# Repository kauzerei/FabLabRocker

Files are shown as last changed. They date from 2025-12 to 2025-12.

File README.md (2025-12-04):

# FabLabRocker

A simple servo-based lab rocker with variable frequency and amplitude.
Designed for DIY PCB fabrication, but can be used for large format photography or chemistry.
3d-design is customizable, written in OpenSCAD and BOSL2.
Measure your container and make the parts that fit ideally.

## PCB

PCB is as simple as it can get.
The project is all about DIY PCB fabrication, so of course it is.
It is one-sided and basically connects a ready-made modules.
Power from a cell does through a switch to DC-DC converter that powers Arduino and the servo.
Two potentiometers are wired to 0 and 5v rails and to analog inputs of Arduino.

### PCB parts list

- Arduino Nano or Pro Micro (change analog pins in code)
- 2 linear Potentiometers, Piher T 16..H or similar, about 25k
- mini DC-DC converter module (noname asymmetric one, based around SDB628xx)
- MG90S Servo
- Any toggle switch to be mounted in 7mm hole
- 18650 holder and cell
- Pin headers/sockets to connect the servo and the switch

## Other parts needed

- 6 M2 thread inserts and 2 M2x8 are nice to have, but not strictly necessary.
- 2 M4x8 screws for the rocking joint. Can also be replaced with almost anything. 

## 3d-printed parts

### Modifying with OpenSCAD

Printable files in STL format are included in this repo.
The ```rocker_top``` should be generated by the user most likely to fit the container.
It's not too scary even if you don't know anything about OpenSCAD.

After installing OpenSCAD run ```git submodule update --init``` and open ```rocker.scad```.
There is "customizer" panel in GUI where you can change the parameters

Model parameters are grouped into self-explanatory categories.
most important are ```bath_width```, ```bath_depth``` which are measurements of container bottom, and ```bath_rounding``` and ```bath_chamfer```, which define corner rounding of the container.
Of the last two parameters only one can be non-zero.

### Printing

Print in default orientation.
2 walls with 30% infill seems fine.
Maybe 3 walls for heavier container with more liquid.

For the ```top_mech``` part use organic supports for the gear.
Other parts are fine without supports.

## Assembly

Assemble the PCB.
KiCad project is in ```agitator_pcb```.

I mounted boost module using pin headers, but any thick wire will do.
I soldered wires and pins to the switch, and pin sockets to the board.
Soldering directly is also OK.
Don't forget to set the voltage of DC-DC converter to 5v.

Customize the mechanical parts and print them.
For the top assembly use 4 thread inserts in ```top_mech```, for mounting the motor use 2 in ```bottom``` and matching M2x8 screws.
Or don't. You can use self-tapping screws or glue or whatever.
The moveable joints are formed by two M4x8 screws.
Any pins 4mm in diamter and 8mm or longer glued to the moving part would be OK.
Press the gear to the shaft of the motor, but fix it with the screw only after the tests.
Mid position of the servo should correspond to horizontal position of the platform.
Fix the gear with M2.5 screw, that comes with each servo when it is oriented correctly. 
PCB is held by the pots, put them through the holes in the enclosure and fix with nuts.

The rocking mechanics just rests on top of the enclosure not beig fixed.
If it bothers you, you can just glue it.
The cell should still be accessible if you do it.  

### Usage

One pot changes the oscillation frequency, the other controls amplitude.
High amplitudes are not achievable with high frequencies.
At high frequencies servo does not have time to rotate to goal positions.
I kept the high frequencies as an imitation of vibrating plate at low amplitudes.

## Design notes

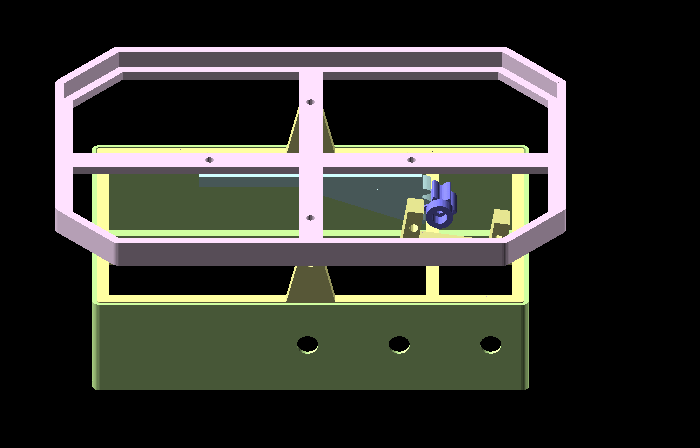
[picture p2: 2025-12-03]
img/animated.gif

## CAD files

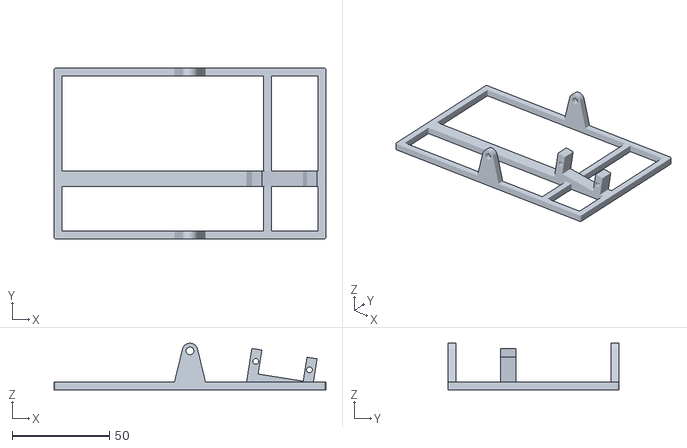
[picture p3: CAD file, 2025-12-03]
3d_print/stl/rocker_bottom.stl
140.0 x 88.0 x 24.0

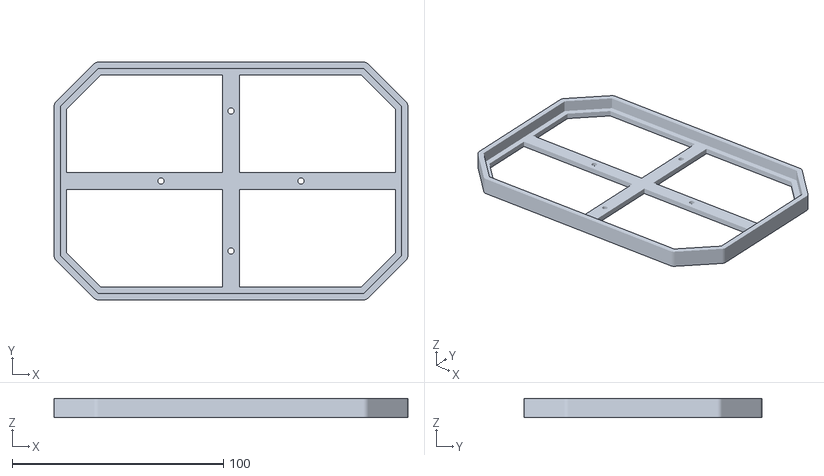
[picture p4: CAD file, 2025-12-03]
3d_print/stl/rocker_top.stl
167.5 x 112.5 x 9.00

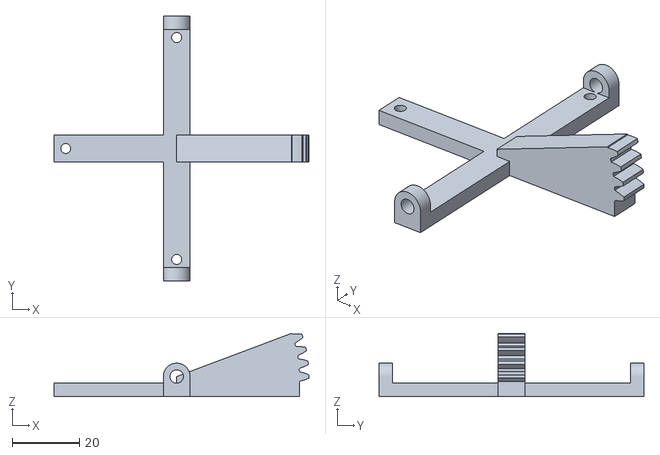
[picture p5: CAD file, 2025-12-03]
3d_print/stl/rocker_top_mech.stl
76.1 x 79.0 x 18.9

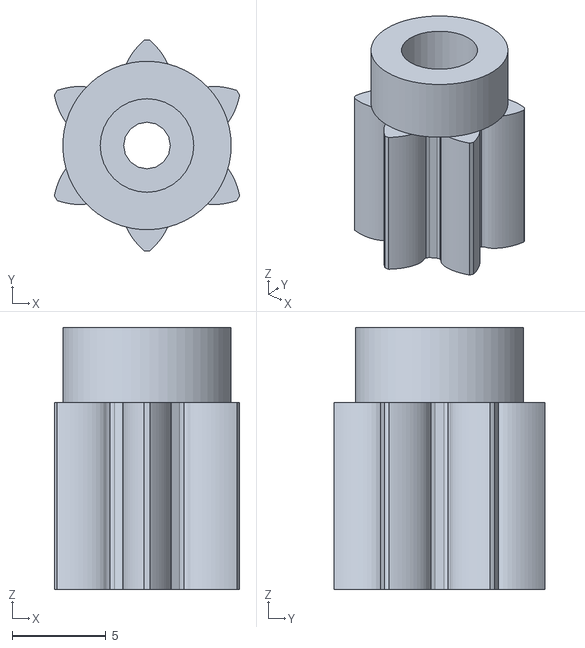
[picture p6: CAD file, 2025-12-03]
3d_print/stl/rocker_servo_gear.stl
9.90 x 11.3 x 14.0

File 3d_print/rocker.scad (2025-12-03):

include <BOSL2/std.scad>
include <BOSL2/gears.scad>
$fa=1/2;
$fs=1/2;
bsl=1/100;

part="NOSTL_all";//[NOSTL_all,top,top_mech,bottom,servo_gear,enclosure]

/* [base (where servo is mounted)] */
base_width=140;
base_depth=88;
base_thickness=4;
base_rounding=1;
height=20;
eyelet_d=4;
eyelet_w=16;
eyelet_gap=0.5;
servo_d=5;
servo_ax=4;
servo_mount_thickness=8;
horn_screw=4;
horn_thickness=1.6;

/* [container holder parameters] */
bath_width=161.5;
bath_depth=106.5;
bath_thickness=3;
bath_lip=6;
bath_rounding=0;//15;
bath_chamfer=18;

/* [general mechanical parameters] */
wall=2; //thinnest load-bearing wall around holes
mech_thickness=4;
screw_d=3; //holes for thread inserts and such
gear_gap=0.0; //extra air between gears
servo_gear=6; //number of teeth
gear_ratio=10; 
gear_pitch=4;
gear_thickness=10;

/* [enclosure] */
enclosure_gap=0.5;
enclosure_wall=1.2;
enclosure_h=25;
holes=[[41,17],[71,17],[11,17]];
hole_d=7;

screw_offset=eyelet_d/2+2*wall+screw_d/2;
dist=gear_dist(circ_pitch=gear_pitch,teeth1=servo_gear,teeth2=servo_gear*gear_ratio)+gear_gap;
max_rotation=90/gear_ratio;
global_rotation=sin(1800*$t)*max_rotation; //to be used in animation maybe
servo_position=[dist*cos(90/gear_ratio),-gear_thickness/2,-dist*sin(90/gear_ratio)];
thickness=eyelet_d+2*wall; //width of parts around eyelets on top and base
cylr=root_radius(mod=gear_pitch/PI,teeth=servo_gear*gear_ratio);

module servo_gear() {
  difference() {
    union() {
      spur_gear(gear_pitch,servo_gear,gear_thickness);
      up(gear_thickness/2) cylinder(d=servo_d+2*wall,h=servo_ax);
    }
    up(gear_thickness/2) cylinder(d=servo_d,h=servo_ax+bsl);
    down(gear_thickness/2+bsl) cylinder(d=2.5,h=gear_thickness+2*bsl);
    up(gear_thickness/2-horn_thickness) cylinder(d=horn_screw,h=gear_thickness,anchor=TOP);
  }
}

module top_mechanics() {
  depth=bath_depth/2+bath_lip-base_depth/2-eyelet_gap;
  cyld=2*root_radius(mod=gear_pitch/PI,teeth=servo_gear*gear_ratio)-2*mech_thickness;
  yflip_copy() difference() { //eyelets
    back(base_depth/2-base_thickness-eyelet_gap-mech_thickness/2)
    difference() {
      union() {
        ycyl(d=eyelet_d+2*wall,h=mech_thickness);
        cube([eyelet_d+2*wall,mech_thickness,eyelet_d/2+wall],anchor=BOTTOM);
      }
      ycyl(d=eyelet_d,h=mech_thickness+bsl);
      back(-base_depth/2-eyelet_gap-depth/2+bath_depth/2) right(screw_offset) down(bsl){
        cylinder(d=screw_d,h=eyelet_d/2+wall);
      }
    }  
  }
  up(eyelet_d/2)
  difference() {
    union() { //bars
      cube([2*cylr,thickness,mech_thickness],anchor=CENTER+BOTTOM);
      cube([cylr,thickness,eyelet_d/2],anchor=LEFT+TOP);
      cube([thickness,base_depth-2*base_thickness-2*eyelet_gap,mech_thickness],anchor=CENTER+BOTTOM);
    }
    for (tr=(cylr-screw_d/2-wall)*[[1,0,0],[0,1,0],[-1,0,0],[0,-1,0]]) translate(tr) { //screw holes
      down(bsl)cylinder(d=screw_d,h=mech_thickness+2*bsl);
    }
  }
  yrot(90) xrot(90) spur_gear(gear_pitch,servo_gear*gear_ratio,thickness,0,hide=floor(servo_gear*(gear_ratio-0.5))-1);
}

module servo_mount() {
  fwd(servo_ax) right(5.45) difference() {
    up(12.5/2)cube([34,servo_mount_thickness,100],anchor=TOP+BACK);
    back(bsl)cube([23.5,servo_mount_thickness+2*bsl,12.5+bsl],anchor=CENTER+BACK);
    back(bsl)right(14)ycyl(d=3,h=servo_mount_thickness+2*bsl,anchor=BACK);
    back(bsl)left(14)ycyl(d=3,h=servo_mount_thickness+2*bsl,anchor=BACK);
  }
}

module top() {
  top_profile=bath_thickness*[[0,0],[1,0],[1,-1],[-1,-1],[-1,bath_lip/bath_thickness],[0,bath_lip/bath_thickness]];
  path=rect([bath_width,bath_depth],chamfer=bath_chamfer,rounding=bath_rounding);
  path_extrude2d(path,closed=true) polygon(top_profile);
  difference() {
    union() {
      cube([bath_width,thickness,bath_thickness],anchor=TOP);
      cube([thickness,bath_depth,bath_thickness],anchor=TOP);
    }
    for (tr=(cylr-screw_d/2-wall)*[[1,0,0],[0,1,0],[-1,0,0],[0,-1,0]]) translate(tr) { //screw holes
      up(bsl)cylinder(d=screw_d,h=bath_thickness+2*bsl,anchor=TOP);
    }
  }  
}

module bottom() {
  linear_extrude(height=base_thickness) difference() { //base
    r=rect([base_width,base_depth],rounding=base_rounding);
    polygon(r);
    polygon(offset(r,r=-base_thickness));
  }
  yflip_copy() difference() { //eyelets
    hull() {
      translate ([0,base_depth/2-base_thickness/2,height]) ycyl(d=eyelet_d+2*wall,h=base_thickness);
      translate ([-eyelet_w/2,base_depth/2-base_thickness,base_thickness]) scale([1,1,0]) cube([eyelet_w,base_thickness,1]);
    }
    translate([0,base_depth/2-base_thickness/2,height]) ycyl(d=eyelet_d,h=base_thickness+2*bsl);
  }
  fwd(gear_thickness/2+servo_ax)cube([base_width,servo_mount_thickness,base_thickness],anchor=BACK+BOTTOM); //bar along motor
  right(cylr+gear_pitch/3)cube([base_thickness,base_depth,base_thickness],anchor=BOTTOM+LEFT); //cross bar
  intersection() {
    cube([base_width,base_depth,100],anchor=BOTTOM);
    up(height) translate(servo_position) yrot(max_rotation) servo_mount();
  }
}

module enclosure(){
  r=rect([base_width,base_depth],rounding=base_rounding);
  difference() {
    union() {
      linear_extrude(height=enclosure_h+2*base_thickness,convexity=4) difference() { //walls
        polygon(offset(r,r=enclosure_gap+enclosure_wall));
        polygon(offset(r,r=enclosure_gap));
      }
      up(enclosure_h+0.5*base_thickness) difference() { 
        linear_extrude(height=base_thickness,center=true) polygon(offset(r,r=enclosure_gap));
        linear_extrude(height=base_thickness+bsl,center=true,scale=[(base_width-2*base_thickness)/(base_width+2*enclosure_gap),(base_depth-2*base_thickness)/(base_depth+2*enclosure_gap)]) polygon(offset(r,r=enclosure_gap));
    }
  }
    fwd(base_depth/2+enclosure_gap+enclosure_wall/2) right(base_width/2) for (hole=holes) {
      left(hole[0]) up(hole[1]) {
        ycyl(d=hole_d,h=enclosure_wall+bsl);
        back(enclosure_wall/2)ycyl(d=16,h=base_thickness+enclosure_gap,anchor=FRONT);
        }
    }
  }
  down(enclosure_wall)linear_extrude(height=enclosure_wall) { //floor
    difference() {
      polygon(offset(r,r=enclosure_gap+enclosure_wall));
      polygon(offset(r,r=-3));
    }
  }
}
{
if (part=="NOSTL_all") {
  down(height) color("#FFFFA0") bottom();
  yrot(global_rotation) {
    up(bath_thickness+mech_thickness+eyelet_d/2+1) color("#FFE0FF")top();
    color("#D0FFFF")top_mechanics();
  }
  yrot(90/gear_ratio)right(dist)yrot(-global_rotation*gear_ratio)yrot(180/servo_gear)xrot(90) color("#8080FF")servo_gear();
  down(height+enclosure_h+base_thickness) color("#D0FFA0")enclosure();
}
if (part=="top") top();
if (part=="top_mech") mirror([0,0,1])top_mechanics();
if (part=="bottom") bottom();
if (part=="servo_gear") servo_gear();
if (part=="enclosure") enclosure();
}
//$vpr=[55,0,360*$t];

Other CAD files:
3d_print/BOSL2/constants.scad
3d_print/BOSL2/nema_steppers.scad
3d_print/BOSL2/screw_drive.scad
3d_print/BOSL2/affine.scad
3d_print/BOSL2/attachments.scad
3d_print/BOSL2/ball_bearings.scad
3d_print/BOSL2/beziers.scad
3d_print/BOSL2/bosl1compat.scad
3d_print/BOSL2/bottlecaps.scad
3d_print/BOSL2/builtins.scad
3d_print/BOSL2/color.scad
3d_print/BOSL2/comparisons.scad
3d_print/BOSL2/coords.scad
3d_print/BOSL2/cubetruss.scad
3d_print/BOSL2/distributors.scad
3d_print/BOSL2/drawing.scad
3d_print/BOSL2/examples/BOSL2logo.scad
3d_print/BOSL2/examples/attachments.scad
3d_print/BOSL2/examples/boolean_geometry.scad
3d_print/BOSL2/examples/fractal_tree.scad
3d_print/BOSL2/examples/lsystems.scad
3d_print/BOSL2/examples/orientations.scad
3d_print/BOSL2/examples/spherical_patch.scad
3d_print/BOSL2/examples/spring_handle.scad
3d_print/BOSL2/examples/worldmap_360x180.scad
3d_print/BOSL2/fnliterals.scad
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

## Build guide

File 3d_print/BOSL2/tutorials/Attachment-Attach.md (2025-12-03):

[Prev: Using align()](Tutorial-Attachment-Align)

# Attachment using attach()

The `attach()` module can stick the child object to the parent object
by matching a designated face on the child to a specified face on the
parent.  Unlike `position()` and `align()`, the `attach()` module may
change the orientation and spin of the child.

## The Parent Coordinate System

When you attach a child object, it appears on the parent relative to
the local coordinate system of the parent at the anchor. 
To understand what this means, imagine the perspective of an ant walking on a
sphere.  The meaning of UP varies depending on where on the sphere the
ant is standing.  If you **attach** a cylinder to the sphere then the cylinder will
be "up" from the ant's perspective.   The first example shows a
cylinder placed with `position()` so it points up in the global parent
coordinate system.  The second example shows how `attach()` points the
cylinder UP from the perspective of an ant standing at the anchor
point on the sphere.  

```openscad-3D
include<BOSL2/std.scad>
sphere(40)
    position(RIGHT+TOP) cylinder(r=8,h=20);
```

```openscad-3D
include<BOSL2/std.scad>
sphere(40)
    attach(RIGHT+TOP) cylinder(r=8,h=20);
```

In the example above, the cylinder's center point is attached to the
sphere, pointing "up" from the perspective of the sphere's surface.
For a sphere, a surface normal is defined everywhere that specifies
what "up" means.  But for other objects, it may not be so obvious.
Usually at edges and corners the direction is the average of the
direction of the faces that meet there.

It's obvious to the ant which direction is UP, and hence corresponds
to the Z axis, on the surface of the sphere she inhabits.  But in
order to define the ant's local coordinate system we also need to
decide where the X and Y directions are.  This is obvious an arbitrary
choice.  In BOSL2 this is called the "spin" direction for the anchor.  

When you specify an anchor for use with attachment you are actually
specifying both an anchor position but also an anchor direction (the Z
axis) and the anchor's spin so that you fully define the parent
coordinate systemer and a spin.  If you want to visualize this
direction you can use anchor arrows.

## Anchor Directions and Anchor Arrows

For the ant on the sphere it is obvious which direction is UP; that
direction corresponds to the Z+ axis.  The location of the X and Y
axes is less clear and in fact it may be arbitrary.  One way that is
useful to show the position and orientation of an anchor point is by
attaching an anchor arrow to that anchor.  As noted before, the small
red flag points in the direction of the anchor's Y+ axis when the spin
is zero.

```openscad-3D
include <BOSL2/std.scad>
cube(18, center=true)
    attach(LEFT+TOP)
        anchor_arrow();
```

For large objects, you can change the size of the arrow with the `s=` argument.

```openscad-3D
include <BOSL2/std.scad>
sphere(d=100)
    attach(LEFT+TOP)
        anchor_arrow(s=50);
```

To show all the standard cardinal anchor points, you can use the [show_anchors()](https://github.com/BelfrySCAD/BOSL2/wiki/attachments.scad#module-show_anchors) module.

```openscad-3D;Big
include <BOSL2/std.scad>
cube(20, center=true)
    show_anchors();
```

```openscad-3D;Big
include <BOSL2/std.scad>
cylinder(h=25, d=25, center=true)
    show_anchors();
```

```openscad-3D;Big
include <BOSL2/std.scad>
sphere(d=40)
    show_anchors();
```

For large objects, you can again change the size of the arrows with the `s=` argument.

```openscad-3D;Big
include <BOSL2/std.scad>
prismoid(150,60,100)
    show_anchors(s=45);
```

## Parent-Child Anchor Attachment (Double Argument Attachment)

The `attach()` module has two different modes of operation,
parent-child anchor attachment and parent anchor attachment.  These
are also called double argument attachment and single argument
attachment.  The parent-child anchor attachment, with two arguments,
is usually easier to use and is more powerful because it supports
alignment.  When just starting out with attachment, we recommend that
you focus on this form of attachment.  

When you use parent-child anchor attachment you give a
parent anchor and a child anchor.  Imagine pointing the anchor arrows
on the two objects directly at each other and pushing them together in
the direction of the arrows until they touch.  In many of the examples
below we show first the two objects with their anchor arrows and then
the result of the attach operation using those anchors.

```openscad-3D
include <BOSL2/std.scad>
cube(50,anchor=BOT) attach(TOP,BOT) anchor_arrow(30);
right(60)cylinder(d1=30,d2=15,h=25) attach(BOT,BOT) anchor_arrow(30);
```

```openscad-3D
include <BOSL2/std.scad>
cube(50,anchor=BOT)
  attach(TOP,BOT) cylinder(d1=30,d2=15,h=25);
```

This example produces the same result as using `align()`, but if the
parent anchor is not horizontal, then the child is reoriented:

```openscad-3D
include <BOSL2/std.scad>
prismoid([50,50],[35,35],h=50,anchor=BOT) attach(RIGHT,BOT) anchor_arrow(30);
right(60)cylinder(d1=30,d2=15,h=25) attach(BOT,BOT) anchor_arrow(30);
```

```openscad-3D
include <BOSL2/std.scad>
prismoid([50,50],[35,35],h=50,anchor=BOT)
  attach(RIGHT,BOT) cylinder(d1=30,d2=15,h=25);
```

In this case we attach the curved side of the cone to a cube by lining
up the anchor arrows:

```openscad-3D
include <BOSL2/std.scad>
cube(50,center=true) attach(RIGHT,BOT) anchor_arrow(30);
right(80)cylinder(d1=30,d2=15,h=25) attach(LEFT,BOT) anchor_arrow(30);
```

```openscad-3D
include <BOSL2/std.scad>
cube(50,center=true)
  attach(RIGHT,LEFT) cylinder(d1=30,d2=15,h=25);
```

Note that this form of attachent overrides any anchor or orientation
specified in the child: **with parent-child anchor attachment the
`anchor=` and `orient=` parameters to the child are ignored.**

When you specify attachment using a pair of anchors, the attached
child can spin around the parent anchor while still being attached at
the designated anchors: specifying the anchors leaves one unspecified
degree of freedom.  As noted earlier, this ambiguity is resolved by anchors having a
defined spin which specifies where the Y+ axis is located.
The way that BOSL2 positions objects can be understood by viewing the
anchor arrows as shown above, or you can remember these rules:
1. When attaching to the TOP or BOTTOM: the FRONT of the child points to the front if possible;  otherwise the TOP of the child points BACK.
2. When attaching to other faces, if possible the child's UP anchor will point UP; otherwise, the BACK of the child points up (so the FRONT is pointed down).  

To show how this works we use this prismoid where the blue arrow is
pointing to the front and the green arrow points up.  Also note that
the front left edge is the only right angle.  

```openscad-3D
include <BOSL2/std.scad>
color_this("orange")
prismoid([8,8],[6,6],shift=-[1,1],h=8) {
     attach(TOP,BOT) anchor_arrow(color=[0,1,0],s=12);
     attach(FWD,BOT) anchor_arrow(s=12);     
}
```

If we attach this to the TOP by the LEFT side then we get the result
below.  Notice how the green UP arrow is pointing back.

```openscad-3D
include <BOSL2/std.scad>
cube(30) attach(TOP,LEFT)
color_this("orange")
  prismoid([8,8],[6,6],shift=-[1,1],h=8) {
    attach(TOP,BOT) anchor_arrow(color=[0,1,0],s=12);
    attach(FWD,BOT) anchor_arrow(s=12);     
  }
```

If we attach to the RIGHT using the same LEFT side anchor on the
prismoid then we get the result below.  Note that the green UP anchor
is pointing UP, in accordance with rule 2 from above.  

```openscad-3D
include <BOSL2/std.scad>
cube(30) attach(RIGHT,LEFT)
color_this("orange")
  prismoid([8,8],[6,6],shift=-[1,1],h=8) {
    attach(TOP,BOT) anchor_arrow(color=[0,1,0],s=12);
    attach(FWD,BOT) anchor_arrow(s=12);     
  }
```

The green UP arrow can always be arranged to point up unless we attach
either the top or bottom to one of the cube's vertical faces.  Here we
attach the bottom so you can still see both arrows.  The blue FRONT
arrow on the object is pointing down, as expected based on rule 2.  

```openscad-3D
include <BOSL2/std.scad>
cube(30) attach(RIGHT,BOT)
color_this("orange")
  prismoid([8,8],[6,6],shift=-[1,1],h=8) {
    attach(TOP,BOT) anchor_arrow(color=[0,1,0],s=12);
    attach(FWD,BOT) anchor_arrow(s=12);     
  }
```

What do you do if the direction the child appears is not the direction
you need?  To address this issue `attach()` provides a `spin=`
parameter which spins the attached child around the axis defined by
the joined anchor vectors.  Here is the last example with a rotation
applied to bring the front anchor back to the front:

```openscad-3D
include <BOSL2/std.scad>
cube(30) attach(RIGHT,BOT,spin=-90)
color_this("orange")
  prismoid([8,8],[6,6],shift=-[1,1],h=8) {
    attach(TOP,BOT) anchor_arrow(color=[0,1,0],s=12);
    attach(FWD,BOT) anchor_arrow(s=12);     
  }
```

Be aware that specifying `spin=` to `attach()` is not equivalent to
using the `spin=` argument to the child.  Unlike `orient=` and
`anchor=`, which are ignored, the child `spin=` argument is still
respected, but it may be difficult to figure out which axis it will
rotate on.  It is more intuitive to ignore the child spin parameter
and only use the spin parameter to `attach()`.  The spin must be
scalar but need not be a multiple of 90 degrees.

```openscad-3D
include <BOSL2/std.scad>
cube(30) attach(RIGHT,BOT,spin=-37)
color_this("orange")
  prismoid([8,8],[6,6],shift=-[1,1],h=8) {
    attach(TOP,BOT) anchor_arrow(color=[0,1,0],s=12);
    attach(FWD,BOT) anchor_arrow(s=12);     
  }
```

By default, `attach()` places the child exactly flush with the surface
of the parent.  Sometimes it's useful to have the child overlap the
parent by translating it into the parent.  You can do this with the
`overlap=` argument to `attach()`.  A positive value will cause the
child to overlap the parent, and a negative value will move the child
away from the parent, leaving a small gap.  In the first example we use a very large value of
overlap so the cube is sunk deeply into the parent.  In the second
example a large negative overlap value raises the child high above the
parent.  

```openscad-3D
include <BOSL2/std.scad>
cuboid(50)
    attach(TOP,BOT,overlap=15)
        color("green")cuboid(20);
```

```openscad-3D
include <BOSL2/std.scad>
cube(50,center=true)
    attach(TOP,BOT,overlap=-20)
        cyl(d=20,h=20);
```

Another feature provided by the double argument form of `attach()` is
alignment, which works in a similar way to `align()`.  You can specify
`align=` to align the attached child to an edge or corner.  The
example below shows five different alignments.  

```openscad-3D;Big
include <BOSL2/std.scad>
module thing(){
  color_this("orange")
    prismoid([8,8],[6,6],shift=-[1,1],h=8) {
      attach(TOP,BOT) anchor_arrow(color=[0,1,0],s=12);
      attach(FWD,BOT) anchor_arrow(s=12);     
    }
}
prismoid([50,50],[35,35],h=25,anchor=BOT){
  attach(TOP,BOT,align=FRONT) thing();
  attach(RIGHT,BOT,align=BOT) thing();    
  attach(RIGHT,BACK,align=FRONT) thing();
  attach(FRONT,BACK,align=BOT,spin=45) thing();
  attach(TOP,RIGHT,align=RIGHT,spin=90) thing();
}
```

As with `align()` if you turn an object 90 degrees it can match up
with parallel edges, but if you turn it an arbitrary angle, a corner
of the child will contact the edge of the parent.  Also like align()
the anchor points of the parent and child are aligned but this does
not necessarily mean that edges line up neatly when the shapes have
varying angles.  This misalignment is visible in the object attached
at the RIGHT and aligned to the FRONT.

You may be wondering why all this fuss with align is necessary.
Couldn't you just attach an object at an anchor on an edge?  When you
do this, the object will be attached using the edge anchor, which is
not perpendicular to the faces of the object.  The example below shows
attachment to an edge anchor and also a corner anchor.  

```openscad-3D
include <BOSL2/std.scad>
cube(30)
   color("orange"){
     attach(RIGHT+FRONT,BOT) 
        prismoid([8,8],[6,6],shift=-[1,1],h=8);
     attach(TOP+LEFT+FWD,BOT)
        prismoid([8,8],[6,6],shift=-[1,1],h=8);
   }
```

When using the `align` option to `attach()` you can also set `inset`,
which works the same way as the `inset` parameter to `align()`.  It
shifts the child away from the edge or edges where it is aligned by
the specified amount.  

```openscad-3D
include <BOSL2/std.scad>
prismoid([50,50],[50,25],25){
  attach(FWD,BOT,align=TOP,inset=3) color("lavender")cuboid(5);
  attach(FWD,BOT,align=BOT+RIGHT,inset=3) color("purple")cuboid(5);
}
```

The last capability provided by `attach()` is to attach the child
**inside** the parent object.  This is useful if you want to subtract
the child from the parent.  Doing this requires using tagged
operations with `diff()` which is explained in more detail below. 
For the examples here, note that the `diff()` and `tag()` operations
that appear cause the child to be subtracted.  We return to the
example that started this section, with anchor arrows shown on the two
objects.  

```openscad-3D
include <BOSL2/std.scad>
cube(50,anchor=BOT) attach(TOP) anchor_arrow(30);
right(60)cylinder(d1=30,d2=15,h=25) attach(TOP) anchor_arrow(30);
```

Inside attachment is activated using `inside=true` and it lines up the
anchor arrows so they point together the **same** direction instead of
opposite directions like regular outside attachment.  The result in
this case is appears below, where we have cut away the front half to
show the interior: 

```openscad-3D
include <BOSL2/std.scad>
back_half(s=200)
diff()
cube(50,anchor=BOT)
  attach(TOP,TOP,inside=true)
    cylinder(d1=30,d2=15,h=25);
```

The top of the cavity has a thin layer on it, which occurs because the
two objects share a face in the difference.  To fix this you can use
the `shiftout` parameter to `attach()`.  In this case you could also
use a negative `overlay` value, but the `shiftout` parameter shifts
out in every direction that is needed, which may be three directions
if you align the child at a corner.  The above example looks like this
with with the shift added:

```openscad-3D
include <BOSL2/std.scad>
back_half(s=200)
diff()
cube(50,anchor=BOT)
  attach(TOP,TOP,inside=true,shiftout=0.01)
    cylinder(d1=30,d2=15,h=25);
```

Here is an example of connecting the same object on the right, but
this time with the BOTTOM anchor.  Note how the BOTTOM anchor is
aligned to the RIGHT so it is parallel and pointing in the same
direction as the RIGHT anchor.  

```openscad-3D
include <BOSL2/std.scad>
back_half(s=200)
diff()
cuboid(50)
  attach(RIGHT,BOT,inside=true,shiftout=0.01)
    cylinder(d1=30,d2=15,h=25);
```

Here is an example where alignment moves the object into the corner,
and we benefit from shiftout providing 3 dimensions of adjustment:

```openscad-3D
include <BOSL2/std.scad>
diff()
cuboid(10)
  attach(TOP,TOP,align=RIGHT+FWD,inside=true,shiftout=.01)
    cuboid([2,5,9]);
```

As with `position()`, with any use of `attach()` you can still apply your own translations and
other transformations even after attaching an object.  However, the
order of operations now matters.  If you apply a translation outside
of the anchor then it acts in the parent's global coordinate system, so the
child moves up in this example, where the light gray shows the
untranslated object.  

```openscad-3D
include <BOSL2/std.scad>
cuboid(50){
  %attach(RIGHT,BOT)
    cyl(d1=30,d2=15,h=25);
  up(13)
    color("green") attach(RIGHT,BOT)
      cyl(d1=30,d2=15,h=25);
}
```

On the other hand, if you put the translation between the attach and
the object in your code, then it will act in the local coordinate system of
the parent at the parent's anchor, so in the example below it moves to the right.  

```openscad-3D
include <BOSL2/std.scad>
cuboid(50){
  %attach(RIGHT,BOT)
    cyl(d1=30,d2=15,h=25);
  color("green") attach(RIGHT,BOT)
    up(13)
      cyl(d1=30,d2=15,h=25);
}
```

Parent-child Anchor attachment with CENTER anchors can be surprising because the anchors
both point upwards, so in the example below, the child's CENTER anchor
points up, so it is inverted when it is attached to the parent cone.
Note that the anchors are CENTER anchors, so the bases of the anchors are
hidden in the middle of the objects.  

```openscad-3D
include <BOSL2/std.scad>
cylinder(d1=30,d2=15,h=25) attach(CENTER) anchor_arrow(40);
right(40)cylinder(d1=30,d2=15,h=25) attach(CENTER) anchor_arrow(40);
```

```openscad-3D
include <BOSL2/std.scad>
cylinder(d1=30,d2=15,h=25)
    attach(CENTER,CENTER)
        cylinder(d1=30,d2=15,h=25);
```

Is is also possible to attach to edges and corners of the parent
object.  The anchors for edges spin the child so its BACK direction is
aligned with the edge.  If the edge belongs to a top or bottom
horizontal face, then the BACK directions will point clockwise around
the face, as seen from outside the shape.  (This is the same direction
required for construction of valid faces in OpenSCAD.)  Otherwise, the
BACK direction will point upwards.

Examine the red flags below, where only edge anchors appear on a
prismoid.  The top face shows the red flags pointing clockwise.
The sloped side edges point along the edges, generally upward, and
the bottom ones appear to point counter-clockwise, but if we viewed
the shape from the bottom they would also appear clockwise.  

```openscad-3D;Big
include <BOSL2/std.scad>
prismoid([100,175],[55,88], h=55)
  for(i=[-1:1], j=[-1:1], k=[-1:1])
    let(anchor=[i,j,k])
       if (sum(v_abs(anchor))==2)
         attach(anchor,BOT)anchor_arrow(40);
```

In this example cylinders sink half-way into the top edges of the
prismoid:

```openscad-3D;Big
include <BOSL2/std.scad>
$fn=16;
r=6;
prismoid([100,175],[55,88], h=55){
   attach([TOP+RIGHT,TOP+LEFT],LEFT,overlap=r/2) cyl(r=r,l=88+2*r,rounding=r);
   attach([TOP+FWD,TOP+BACK],LEFT,overlap=r/2) cyl(r=r,l=55+2*r, rounding=r);   
}
```

This type of edge attachment is useful for attaching 3d edge masks to
edges:

```openscad-3D;Big
include <BOSL2/std.scad>
$fn=32;
diff()
cuboid(75)
   attach([FRONT+LEFT, FRONT+RIGHT, BACK+LEFT, BACK+RIGHT],
          FWD+LEFT,inside=true)
     rounding_edge_mask(l=76, r1=8,r2=28);
```

## Parent Anchor Attachment (Single Argument Attachment)

The second form of attachment is parent anchor attachment, which just
uses a single argument.  This form of attachment is less useful in
general and does not provide alignment.  When you give `attach()` a parent anchor but no child anchor it
orients the child according to the parent anchor direction but then
simply places the child based on its internally defined anchor at the
parent anchor position.  For most objects the default anchor is the
CENTER anchor, so objects will appear sunk half-way into the parent.

```openscad-3D
include <BOSL2/std.scad>
cuboid(30)
    attach(TOP)
        color("green")cuboid(10);
```

Some objects such as `cylinder()`, `prismoid()`, and `anchor_arrow()` have default anchors on the bottom, so they will appear
on the surface.  For objects like this you can save a little bit of
typing by using parent anchor attachment.  But in the case of `cube()`
the anchor is not centered, so the result is:

```openscad-3D
include <BOSL2/std.scad>
cube(30)
    attach(TOP)
        color("green")cube(10);
```

In order to make single argument attachment produce the results you
need you will probably need to change the child anchor.  Note that unlike
parent-child anchor attachment, **with parent anchor attachment the `anchor=` and `orient=` arguments
are respected.**  We could therefore place a cuboid like this:

```openscad-3D
include <BOSL2/std.scad>
cuboid(30)
  attach(RIGHT)
      color("green")cuboid(10,anchor=BOT);
```

If you need to place a cuboid at the anchor point but need it anchored
relative to one of the bottom edge or corner anchors then you can do
that with parent anchor attachment:

```openscad-3D
include <BOSL2/std.scad>
cuboid(30)
  attach(RIGHT)
      color("green")cuboid(10,anchor=BOT+FWD);
```

Another case where single argument attachment is useful is when the
child doesn't have proper attachment support.
If you use double argument attachment in such cases the results will
be incorrect because the child doesn't properly respond to the
internally propagated anchor directives.  With single argument
attachment, this is not a problem: the origin
of the child will be placed at the parent anchor point.  One module
without attachment support is `linear_extrude()`.  

```openscad-3D
include <BOSL2/std.scad>
cuboid(20)
  attach(RIGHT)
     color("red")linear_extrude(height=2) star(n=7,ir=3,or=7);
```

As noted earlier, you can set `orient=` for children with parent
anchor attachment, though the behavior may not be intuitive because
the attachment process transforms the coordinate system and the
orientation is done in the attached coordinate system.  It may be
helpful to start with the object attached to TOP and recall the rules
from the previous section about how orientation works.  The same rules
apply here.  Note that the forward arrow is pointing down after
attaching the object on the RIGHT face.

```openscad-3D
include <BOSL2/std.scad>
cuboid(20){
  attach(RIGHT)
     color_this("red")cuboid([2,4,8],orient=RIGHT,anchor=RIGHT)
        attach(FWD) anchor_arrow();
  attach(TOP)
     color_this("red")cuboid([2,4,8],orient=RIGHT,anchor=RIGHT)
            attach(FWD) anchor_arrow();
}
```

## Positioning and Attaching Multiple Children

You can attach or position more than one child at a time by enclosing them all in braces:

```openscad-3D
include <BOSL2/std.scad>
cube(50, center=true) {
    attach(TOP) cylinder(d1=50,d2=20,h=20);
    position(RIGHT) cylinder(d1=50,d2=20,h=20);
}
```

If you want to attach the same shape to multiple places on the same parent, you can pass the
desired anchors as a list to the `attach()` or `position()` modules:

```openscad-3D
include <BOSL2/std.scad>
cube(50, center=true)
    attach([RIGHT,FRONT],TOP) cylinder(d1=35,d2=20,h=25);
```

```openscad-3D
include <BOSL2/std.scad>
cube(50, center=true)
    position([TOP,RIGHT,FRONT]) cylinder(d1=35,d2=20,h=25);
```

## Attaching 2D Children

You can use attachments in 2D as well.  As usual for the 2D case you
can use TOP and BOTTOM as alternative to BACK and FORWARD.  With
parent-child anchor attachment you cannot use the spin parameter to
`attach()` nor can you specify spin to the child.  Spinning the child
on the Z axis would rotate the anchor arrows out of alignment.  

```openscad-2D
include <BOSL2/std.scad>
rect(50){
    attach(RIGHT,FRONT)
        color("red")trapezoid(w1=30,w2=0,h=30);
    attach(LEFT,FRONT,align=[FRONT,BACK],inset=3)
        color("green") trapezoid(w1=25, w2=0,h=30);
}
```

```openscad-2D
include <BOSL2/std.scad>
diff()
circle(d=50){
    attach(TOP,BOT,overlap=5)
        trapezoid(w1=30,w2=0,h=30);
    attach(BOT,BOT,inside=true)
        tag("remove")
        trapezoid(w1=30,w2=0,h=30);
}        
```

[Next: Attachable Parts](Tutorial-Attachment-Parts)

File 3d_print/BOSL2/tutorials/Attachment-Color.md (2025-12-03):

[Prev: Attachable Parts](Tutorial-Attachment-Parts)

## Coloring Attachables
Usually, when coloring a shape with the `color()` module, the parent color overrides the colors of
all children.  This is often not what you want:

```openscad-3D
include <BOSL2/std.scad>
$fn = 24;
color("red") spheroid(d=3) {
    attach(CENTER,BOT) color("white") cyl(h=10, d=1) {
        attach(TOP,BOT) color("green") cyl(h=5, d1=3, d2=0);
    }
}
```

If you use the `recolor()` module, however, the child's color
overrides the color of the parent.  This is probably easier to understand by example:

```openscad-3D
include <BOSL2/std.scad>
$fn = 24;
recolor("red") spheroid(d=3) {
    attach(CENTER,BOT) recolor("white") cyl(h=10, d=1) {
        attach(TOP,BOT) recolor("green") cyl(h=5, d1=3, d2=0);
    }
}
```

Be aware that `recolor()` will only work if you avoid using the native
`color()` module.  Also note that `recolor()` still affects all its
children.  If you want to color an object without affecting the
children you can use `color_this()`.  See the difference below:

```openscad-3D
include <BOSL2/std.scad>
$fn = 24;
recolor("red") spheroid(d=3) {
    attach(CENTER,BOT) recolor("white") cyl(h=10, d=1) {
        attach(TOP,BOT)  cyl(h=5, d1=3, d2=0);
    }
}
right(5)
recolor("red") spheroid(d=3) {
    attach(CENTER,BOT) color_this("white") cyl(h=10, d=1) {
        attach(TOP,BOT)  cyl(h=5, d1=3, d2=0);
    }
}
```

Similar modules exist to provide access to the highlight and
background modifiers.   You can specify `highlight()` and then later
`highlight(false)` to control the use of the `#` modifier.  Similarly
you can use `ghost()` and `ghost(false)` to provide more control of
the `%` modifier.  And as with color, you can also use
`highlight_this()` and `ghost_this()` to affect just one child without
affecting its descendents.  

As with all of the attachable features, these color, highlight and ghost modules only work
on attachable objects, so they will have no effect on objects you
create using `linear_extrude()` or `rotate_extrude()`.  

[Next: Tagged Operations with Attachments](Tutorial-Attachment-Tags)

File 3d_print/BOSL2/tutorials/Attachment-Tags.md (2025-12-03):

[Prev: Using Color with Attachments](Tutorial-Attachment-Color)

# Tagged Operations

BOSL2 introduces the concept of tags.  Tags are names that can be given to attachables, so that
you can refer to them when performing `diff()`, `intersect()`, and `conv_hull()` operations.
Each object can have no more than one tag at a time.  The reason that
tagged operations are important is that they allow you to perform
operations on objects that are at different levels in the parent-child
hierarchy.  The most common example is to use `attach()` to create a
child but subtract it from the parent.

To tag an object preceed the object with the `tag()` module and give
it a name: `tag("my_cube") cube(10)`.  The tag will apply to the
object and all of its children until another tag module.  If you need
to remove a tag you can use `tag("")`.  If you need to tag just one
object and do not want to tag any of its descendents you can do this
using `tag_this(name) object();`

### `diff([remove], [keep])`
The `diff()` operator is used to difference away all shapes marked with the tag(s) given to
`remove`, from the other shapes.  

For example, to difference away a child cylinder from the middle of a parent cube, you can
do this:

```openscad-3D
include <BOSL2/std.scad>
diff("hole")
cube(100, center=true)
    tag("hole")cylinder(h=101, d=50, center=true);
```

The `keep=` argument takes tags for shapes that you want to keep in the output.

```openscad-3D
include <BOSL2/std.scad>
diff("dish", keep="antenna")
cube(100, center=true)
    attach([FRONT,TOP], overlap=33) {
        tag("dish") cylinder(h=33.1, d1=0, d2=95);
        tag("antenna") cylinder(h=33.1, d=10);
    }
```

Remember that tags applied with `tag()` are inherited by children.  In this case, we need to explicitly
untag the first cylinder (or change its tag to something else), or it
will inherit the "keep" tag and get kept.  

```openscad-3D
include <BOSL2/std.scad>
diff("hole", "keep")
tag("keep")cube(100, center=true)
    attach([RIGHT,TOP]) {
        tag("") cylinder(d=95, h=5);
        tag("hole") cylinder(d=50, h=11, anchor=CTR);
    }
```

You can apply a tag that is not propagated to the children using
`tag_this()`.  The above example could then be redone:

```openscad-3D
diff("hole", "keep")
tag_this("keep")cube(100, center=true)
    attach([RIGHT,TOP]) {
        cylinder(d=95, h=5);
        tag("hole") cylinder(d=50, h=11, anchor=CTR);
    }
```    

You can of course apply `tag()` to several children.

```openscad-3D
include <BOSL2/std.scad>
diff("hole")
cube(100, center=true)
    attach([FRONT,TOP], overlap=20)
        tag("hole") {
            cylinder(h=20.1, d1=0, d2=95);
            down(10) cylinder(h=30, d=30);
        }
```

Many of the modules that use tags have default values for their tags.  For diff the default
remove tag is "remove" and the default keep tag is "keep".  In this example we rely on the
default values:

```openscad-3D
include <BOSL2/std.scad>
diff()
sphere(d=100) {
    tag("keep")xcyl(d=40, l=120);
    tag("remove")cuboid([40,120,100]);
}
```

The parent object can be differenced away from other shapes.  Tags are inherited by children,
though, so you will need to set the tags of the children as well as the parent.

```openscad-3D
include <BOSL2/std.scad>
diff("hole")
tag("hole")cube([20,11,45], center=true)
    tag("body")cube([40,10,90], center=true);
```

Tags (and therefore tag-based operations like `diff()`) only work correctly with attachable
children.  However, a number of built-in modules for making shapes are *not* attachable.
Some notable non-attachable modules are `text()`, `linear_extrude()`, `rotate_extrude()`,
`polygon()`, `polyhedron()`, `import()`, `surface()`, `union()`, `difference()`,
`intersection()`, `offset()`, `hull()`, and `minkowski()`.

To allow you to use tags-based operations with non-attachable shapes, you can wrap them with the
`force_tag()` module to specify their tags.  For example:

```openscad-3D
include <BOSL2/std.scad>
diff("hole")
cuboid(50)
  attach(TOP)
    force_tag("hole")
      rotate_extrude()
        right(15)
          square(10,center=true);
```

### `intersect([intersect], [keep])`

To perform an intersection of attachables, you can use the `intersect()` module.  This is
specifically intended to address the situation where you want intersections involving a parent
and a child, something that is impossible with the native `intersection()` module.  This module
treats the children in three groups: objects matching the `intersect` tags, objects matching
the tags listed in `keep` and the remaining objects that don't match any listed tags.  The
intersection is computed between the union of the `intersect` tagged objects and the union of
the objects that don't match any listed tags.  Finally the objects listed in `keep` are union
ed with the result.  

In this example the parent (untagged) is intersected with a conical
bounding shape, which is tagged with the intersect tag.

```openscad-3D
include <BOSL2/std.scad>
intersect("bounds")
cube(100, center=true)
    tag("bounds") cylinder(h=100, d1=120, d2=95, center=true, $fn=72);
```

In this example the child objects are intersected with the bounding box parent.  

```openscad-3D
include <BOSL2/std.scad>
intersect("pole cap")
cube(100, center=true)
    attach([TOP,RIGHT]) {
        tag("pole")cube([40,40,80],center=true);
        tag("cap")sphere(d=40*sqrt(2));
    }
```

The default `intersect` tag is "intersect" and the default `keep` tag is "keep".  Here is an
example where "keep" is used to keep the pole from being removed by the intersection. 

```openscad-3D
include <BOSL2/std.scad>
intersect()
cube(100, center=true) {
    tag("intersect")cylinder(h=100, d1=120, d2=95, center=true, $fn=72);
    tag("keep")zrot(45) xcyl(h=140, d=20, $fn=36);
}
```

### `conv_hull([keep])`
You can use the `conv_hull()` module to hull shapes together.  Objects
marked with the keep tags are excluded from the hull and unioned into the final result.
The default keep tag is "keep".  

```openscad-3D
include <BOSL2/std.scad>
conv_hull()
cube(50, center=true) {
    cyl(h=100, d=20);
    tag("keep")xcyl(h=100, d=20);
}
```

[Next: Edge Profiling with Attachment](Tutorial-Attachment-Edge-Profiling)

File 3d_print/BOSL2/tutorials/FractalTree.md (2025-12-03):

# Fractal Tree Tutorial

<!-- TOC -->

### Start with a Tree Trunk

Firstoff, include the BOSL2 library, then make a starting module that just has a tapered cylinder for the tree trunk.

```openscad-3D
include <BOSL2/std.scad>
module tree(l=1500, sc=0.7)
    cylinder(h=l, d1=l/5, d2=l/5*sc);
tree();
```

### Attaching a Branch

You can attach a branch to the top of the trunk by using `attach()` as a child of the trunk cylinder.

```openscad-3D
include <BOSL2/std.scad>
module tree(l=1500, sc=0.7)
    cylinder(h=l, d1=l/5, d2=l/5*sc)
        attach(TOP)
            yrot(30) cylinder(h=l*sc, d1=l/5*sc, d2=l/5*sc*sc);
tree();
```

### Replicating the Branch

Instead of attaching each branch individually, you can make multiple copies of one branch, that are rotated relative to each other.

```openscad-3D
include <BOSL2/std.scad>
module tree(l=1500, sc=0.7)
    cylinder(h=l, d1=l/5, d2=l/5*sc)
        attach(TOP)
            zrot_copies(n=2)  // Replicate that branch
                yrot(30) cylinder(h=l*sc, d1=l/5*sc, d2=l/5*sc*sc);
tree();
```

### Use Recursion

Since branches look much like the main trunk, we can make the tree recursive. Don't forget the termination clause, or else it'll try to recurse forever!

```openscad-Med
include <BOSL2/std.scad>
module tree(l=1500, sc=0.7, depth=10)
    cylinder(h=l, d1=l/5, d2=l/5*sc)
        attach(TOP)
            if (depth>0)  { // Important!
                zrot_copies(n=2)
                yrot(30) tree(depth=depth-1, l=l*sc, sc=sc);
            }
tree();
```

### Make it Not Flat

A flat planar tree isn't what we want, so lets bush it out a bit by rotating each level 90 degrees.

```openscad-Med
include <BOSL2/std.scad>
module tree(l=1500, sc=0.7, depth=10)
    cylinder(h=l, d1=l/5, d2=l/5*sc)
        attach(TOP)
            if (depth>0) {
                zrot(90)  // Bush it out
                zrot_copies(n=2)
                yrot(30) tree(depth=depth-1, l=l*sc, sc=sc);
            }
tree();
```

### Adding Leaves

Let's add leaves. They look much like squashed versions of the standard teardrop() module, so lets use that.

```openscad-Big
include <BOSL2/std.scad>
module tree(l=1500, sc=0.7, depth=10)
    cylinder(h=l, d1=l/5, d2=l/5*sc)
        attach(TOP)
            if (depth>0) {
                zrot(90)
                zrot_copies(n=2)
                yrot(30) tree(depth=depth-1, l=l*sc, sc=sc);
            } else {
                yscale(0.67)
                teardrop(d=l*3, l=1, anchor=BOT, spin=90);
            }
tree();
```

### Adding Color

We can finish this off with some color. The `color()` module will force all it's children and
their descendants to the new color, even if they were colored before. The `recolor()` module,
however, will only color children and decendants that don't already have a color set by a more
nested `recolor()`.

```openscad-Big
include <BOSL2/std.scad>
module tree(l=1500, sc=0.7, depth=10)
    recolor("lightgray")
    cylinder(h=l, d1=l/5, d2=l/5*sc)
        attach(TOP)
            if (depth>0) {
                zrot(90)
                zrot_copies(n=2)
                yrot(30) tree(depth=depth-1, l=l*sc, sc=sc);
            } else {
                recolor("springgreen")
                yscale(0.67)
                teardrop(d=l*3, l=1, anchor=BOT, spin=90);
            }
tree();
```

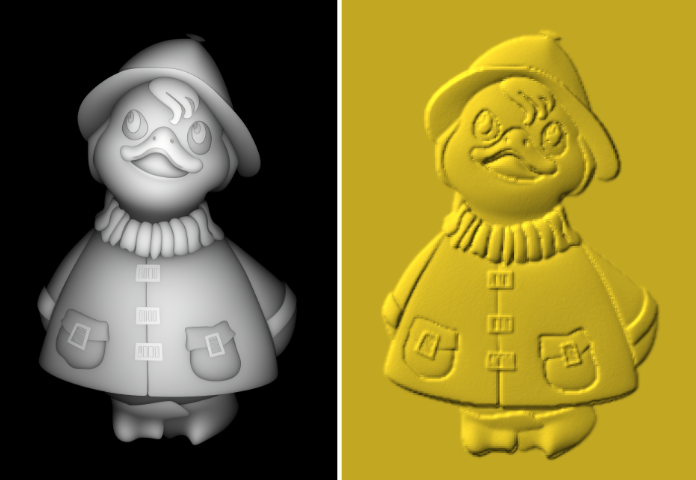
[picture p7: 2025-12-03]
3d_print/BOSL2/images/WilburTex02.png

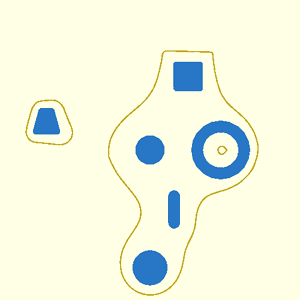
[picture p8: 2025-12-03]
3d_print/BOSL2/images/metaball_demo2d.gif

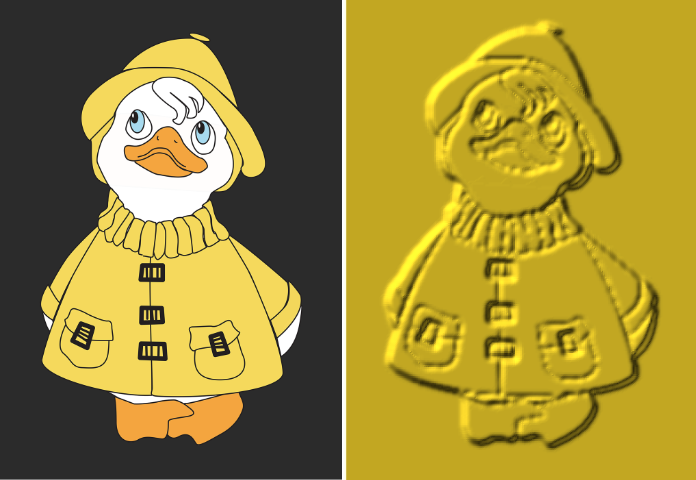
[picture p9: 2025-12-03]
3d_print/BOSL2/images/WilburTex01.png

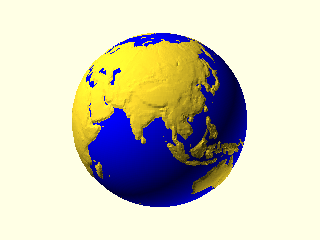
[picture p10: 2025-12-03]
3d_print/BOSL2/images/globe_animation.png

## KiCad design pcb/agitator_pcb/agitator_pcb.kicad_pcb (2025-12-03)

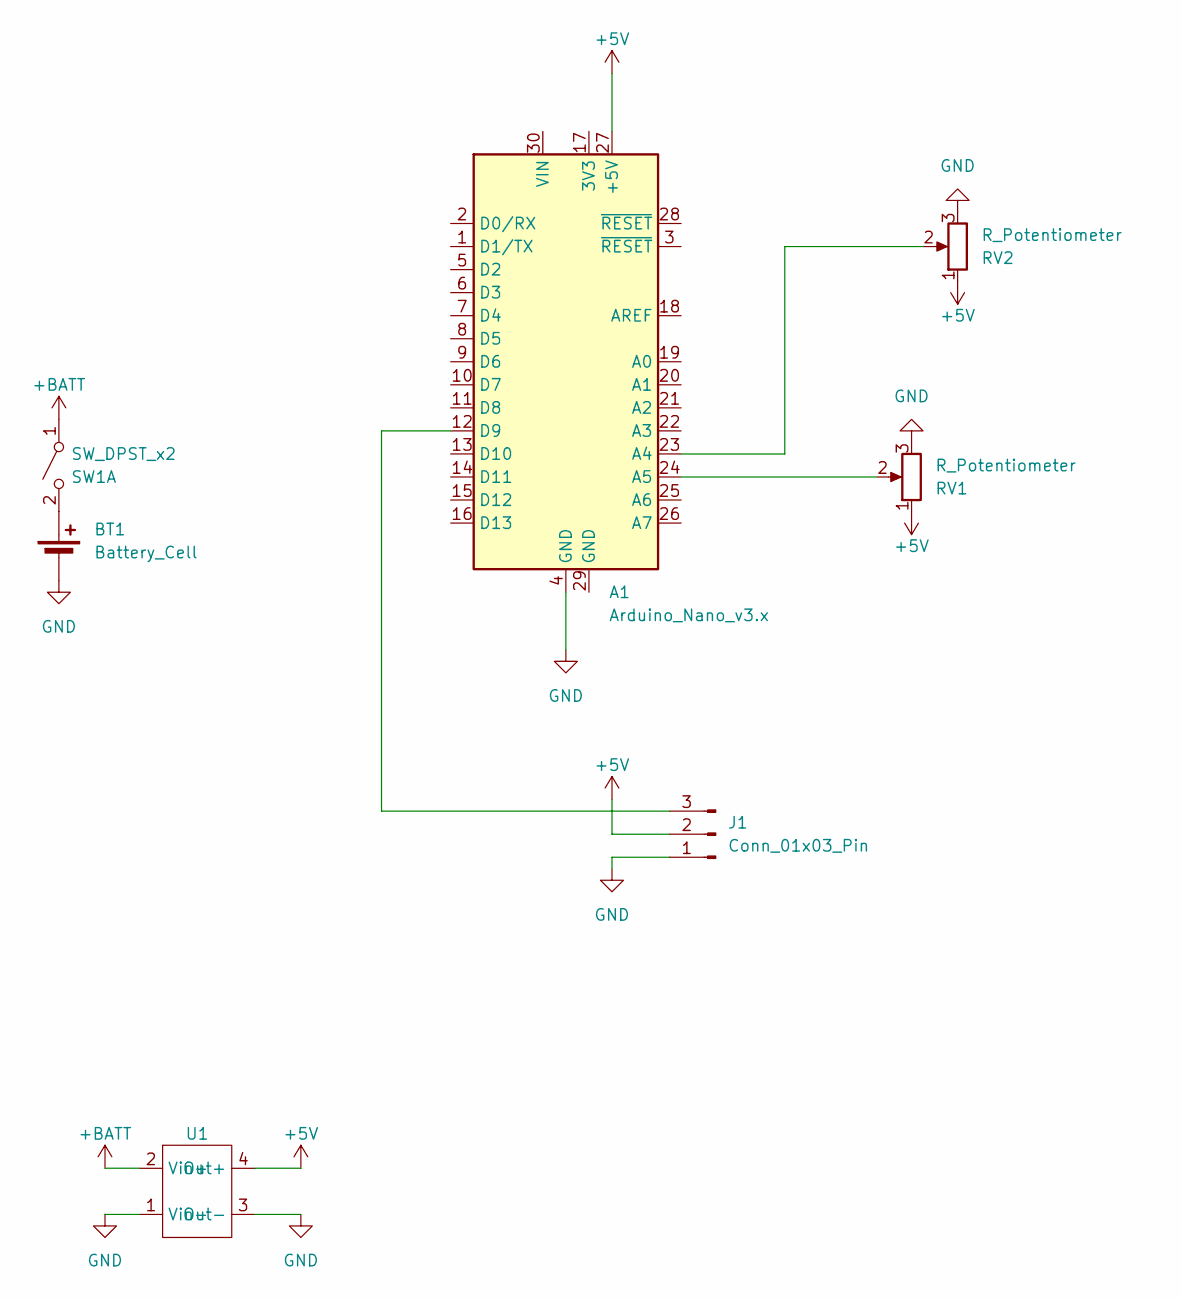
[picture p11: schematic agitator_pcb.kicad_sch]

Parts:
A1: Arduino_Nano_v3.x; Arduino_Nano
BT1: Battery_Cell; BatteryHolder_MPD_BH-18650-PC
J1: Conn_01x03_Pin; PinHeader_1x03_P2.54mm_Vertical
RV1, RV2: R_Potentiometer; Potentiometer_Piher_T-16H_Single_Horizontal
SW1: SW_DPST_x2; PinSocket_1x02_P2.54mm_Vertical
U1: dc-dc module

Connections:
+5V: A1.27 (+5V), J1.2, RV1.1, RV2.1, U1.4 (Out+)
+BATT: SW1.1 (A), U1.2 (Vin+)
GND: A1.4 (GND), BT1.2 (-), J1.1, RV1.3, RV2.3, U1.1 (Vin-), U1.3 (Out-)
unnamed: A1.23 (A4), RV2.2
unnamed: A1.24 (A5), RV1.2
unnamed: A1.12 (D9), J1.3
unnamed: BT1.1 (+), SW1.2 (B)

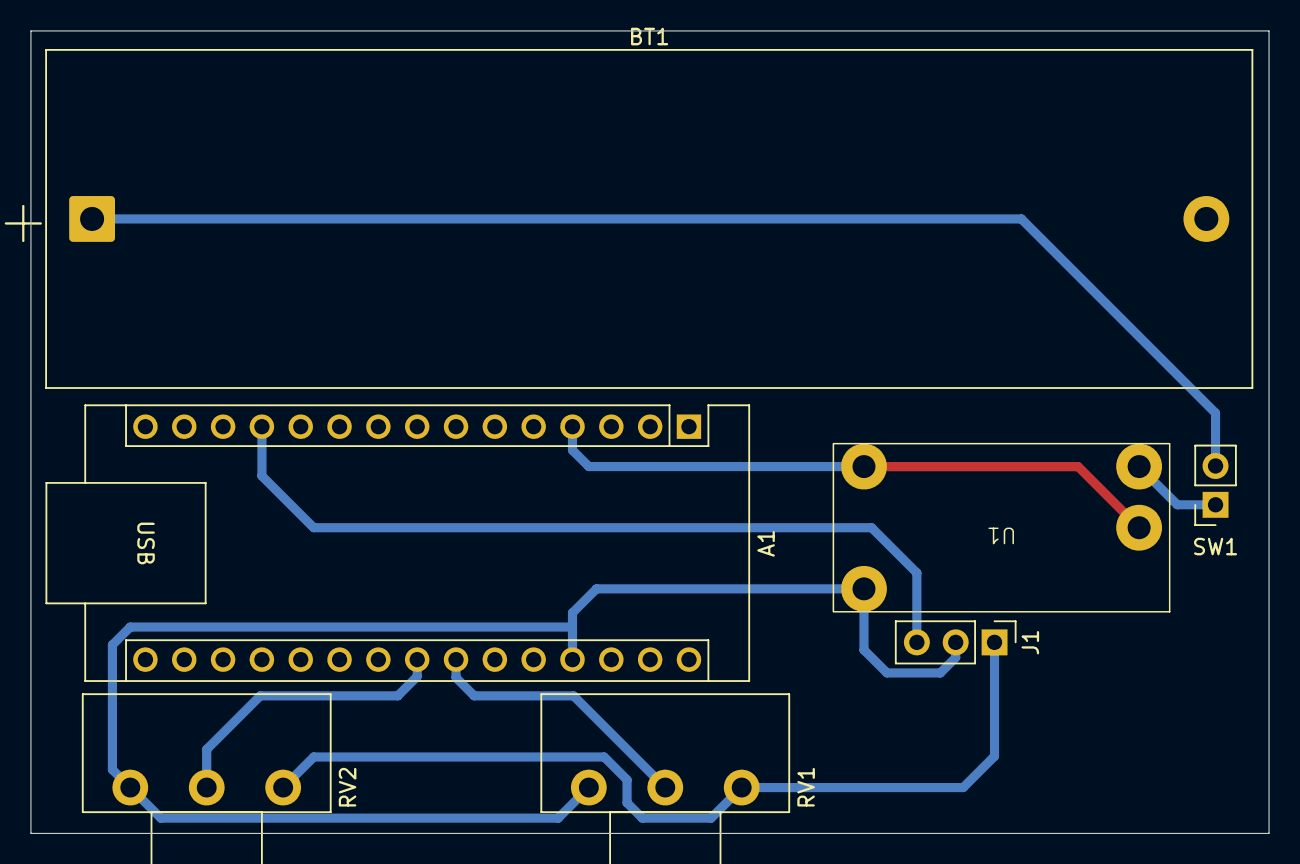
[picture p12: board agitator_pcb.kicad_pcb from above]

Board: 2 copper layers, 81.0 x 52.5 mm, 7 parts (0 on the bottom side), 7 nets.

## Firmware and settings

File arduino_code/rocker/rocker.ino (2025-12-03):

#include <Servo.h>
#include <math.h>

Servo servo;
//frequency:
int freq_pin=A4; //input pin
int freq_pot; //pot read value
float freq; //value in Hz

//amplitude:
int amp_pin=A5; //input pin
int amp_pot; //pot read value
float amp; //value in degrees (max 90)

float srv_vals[256]; //precalculated sin values
byte index=0; //current index in srv_vals array
int skip; //number of bits to skip in index
unsigned long switchtime; //value of micros() to send next goal to servo
const float servo_freq=100; //100 works better than theoretical 50 for some reason

//maybe precalculate freq and skip values just in case?
//can they possibly take more than 1/100s?
//works as is, but think about it

void setup() {
  servo.attach(9);
  for (int i=0;i<256;i++) srv_vals[i]=sin(float(i)*2.0*PI/256.0); //precalculate sin values
  switchtime=micros();
}

void loop() {
  freq_pot=1024-analogRead(freq_pin); //can remove 1024- to invert the pot direction
  freq=pow(10.0,(float(freq_pot-512)/512.0)); //map 0-1023 values to exp frequency scale from 0.1 to 10 hz
  amp_pot=1024-analogRead(amp_pin); //can remove 1024- to invert the pot direction
  amp=90.0*amp_pot/1024.0;
  skip=max(0,ceil(8+log(freq/servo_freq)/log(2)));
  index=(index&(255<<skip))+(1<<skip); //clear last "skip" bits and add smallest positive number with "skip" zeroes
  switchtime=switchtime+1000000*pow(2,skip-8)/freq;
  while(micros()<switchtime);
  servo.write(90+amp*srv_vals[index]);
}
